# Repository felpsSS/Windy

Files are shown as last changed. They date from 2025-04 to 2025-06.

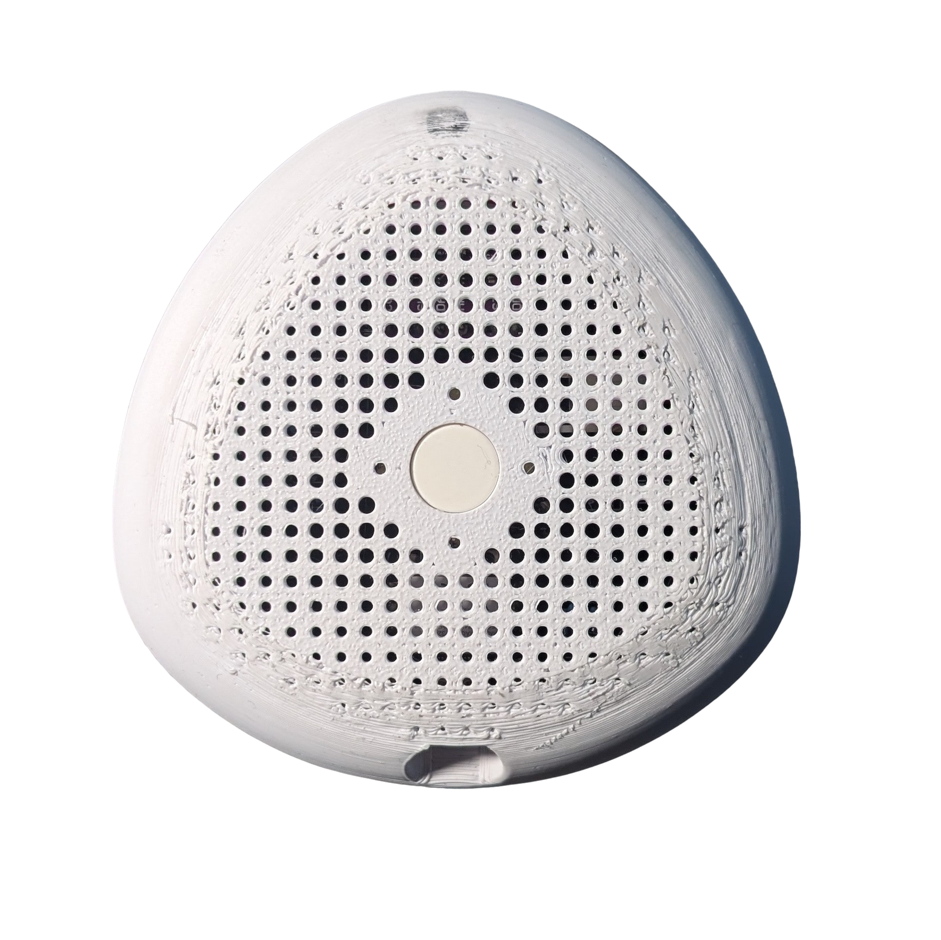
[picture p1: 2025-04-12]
media/FinalProduct.png

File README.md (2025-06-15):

# 🌬️ Windy: Build Your Air Quality Device!



Welcome to the **Windy** repository! This folder contains everything you need to build our air quality device. Whether you are a hobbyist, student, or professional, you will find useful resources here. 

## 📦 Table of Contents

- [Introduction](#introduction)
- [Features](#features)
- [Getting Started](#getting-started)
- [Hardware Components](#hardware-components)
- [Software Setup](#software-setup)
- [3D Printing](#3d-printing)
- [Mobile Application](#mobile-application)
- [PCB Design](#pcb-design)
- [Contributing](#contributing)
- [License](#license)
- [Contact](#contact)
- [Releases](#releases)

## 📜 Introduction

Air quality is vital for our health and well-being. With the **Windy** device, you can monitor air quality in real-time. This project combines various technologies, including sensors, microcontrollers, and mobile applications. 

## 🌟 Features

- Real-time air quality monitoring
- User-friendly mobile application for Android and iOS
- Open-source design for easy customization
- 3D-printed housing for a sleek look
- Easy-to-follow instructions

## 🚀 Getting Started

To get started with the **Windy** project, follow these steps:

1. **Clone the Repository**
   ```bash
   git clone https://github.com/felpsSS/Windy.git
   ```

2. **Navigate to the Directory**
   ```bash
   cd Windy
   ```

3. **Check the Documentation**
   Refer to the `docs` folder for detailed instructions.

## 🛠️ Hardware Components

To build the **Windy** device, you will need the following components:

- **ESP32 Microcontroller**: This will be the brain of your device.
- **Air Quality Sensor**: Choose a sensor that meets your needs (e.g., MQ-135).
- **Power Supply**: Ensure you have a reliable power source.
- **3D Printed Case**: You can find the design files in the `3D-Print` folder.

### Recommended Components

| Component | Description |
|---|---|
| ESP32 | Dual-core microcontroller |
| MQ-135 Sensor | Measures air quality |
| Battery Pack | For portable use |
| Jumper Wires | For connections |

## 💻 Software Setup

The software setup involves several steps:

1. **Install the Arduino IDE**: Download from the [official website](https://www.arduino.cc/en/software).
2. **Install ESP32 Board Support**: Follow the instructions in the Arduino IDE to add ESP32 support.
3. **Upload the Code**: Open the `Windy.ino` file and upload it to your ESP32.

### Libraries Required

Make sure to install the following libraries in the Arduino IDE:

- `DHT sensor library`
- `WiFi library`
- `HTTPClient library`

## 🖨️ 3D Printing

To create the housing for your **Windy** device, you will need to 3D print the case. The STL files are located in the `3D-Print` folder. 

### Printing Guidelines

- **Material**: Use PLA or ABS for durability.
- **Layer Height**: 0.2 mm for a good balance of quality and speed.
- **Infill**: 20% should be sufficient.

## 📱 Mobile Application

The **Windy** mobile application is available for both Android and iOS. It allows you to monitor air quality data from your device.

### Features of the App

- Real-time data display
- Historical data tracking
- Alerts for poor air quality
- User-friendly interface

### Installation

You can download the mobile app from the respective app stores. 

## 🛠️ PCB Design

The PCB design files are included in the repository. You can modify them as needed. 

### Design Software

We recommend using KiCAD or Eagle for PCB design. 

## 🤝 Contributing

We welcome contributions! If you want to improve the **Windy** project, please follow these steps:

1. Fork the repository.
2. Create a new branch.
3. Make your changes.
4. Submit a pull request.

## 📜 License

This project is licensed under the MIT License. See the `LICENSE` file for details.

## 📞 Contact

For questions or feedback, feel free to reach out:

- **Email**: your-email@example.com
- **GitHub**: [felpsSS](https://github.com/felpsSS)

## 🚀 Releases

For the latest updates and releases, visit our [Releases](https://github.com/felpsSS/Windy/releases) section. You can download the necessary files and execute them as needed.

---

Thank you for checking out the **Windy** project! We hope you enjoy building your air quality device. For any further questions, please refer to the documentation or contact us directly.

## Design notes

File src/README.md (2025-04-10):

# hci_air_quality

A new Flutter project.

## Getting Started

This project is a starting point for a Flutter application.

A few resources to get you started if this is your first Flutter project:

- [Lab: Write your first Flutter app](https://docs.flutter.dev/get-started/codelab)
- [Cookbook: Useful Flutter samples](https://docs.flutter.dev/cookbook)

For help getting started with Flutter development, view the
[online documentation](https://docs.flutter.dev/), which offers tutorials,
samples, guidance on mobile development, and a full API reference.

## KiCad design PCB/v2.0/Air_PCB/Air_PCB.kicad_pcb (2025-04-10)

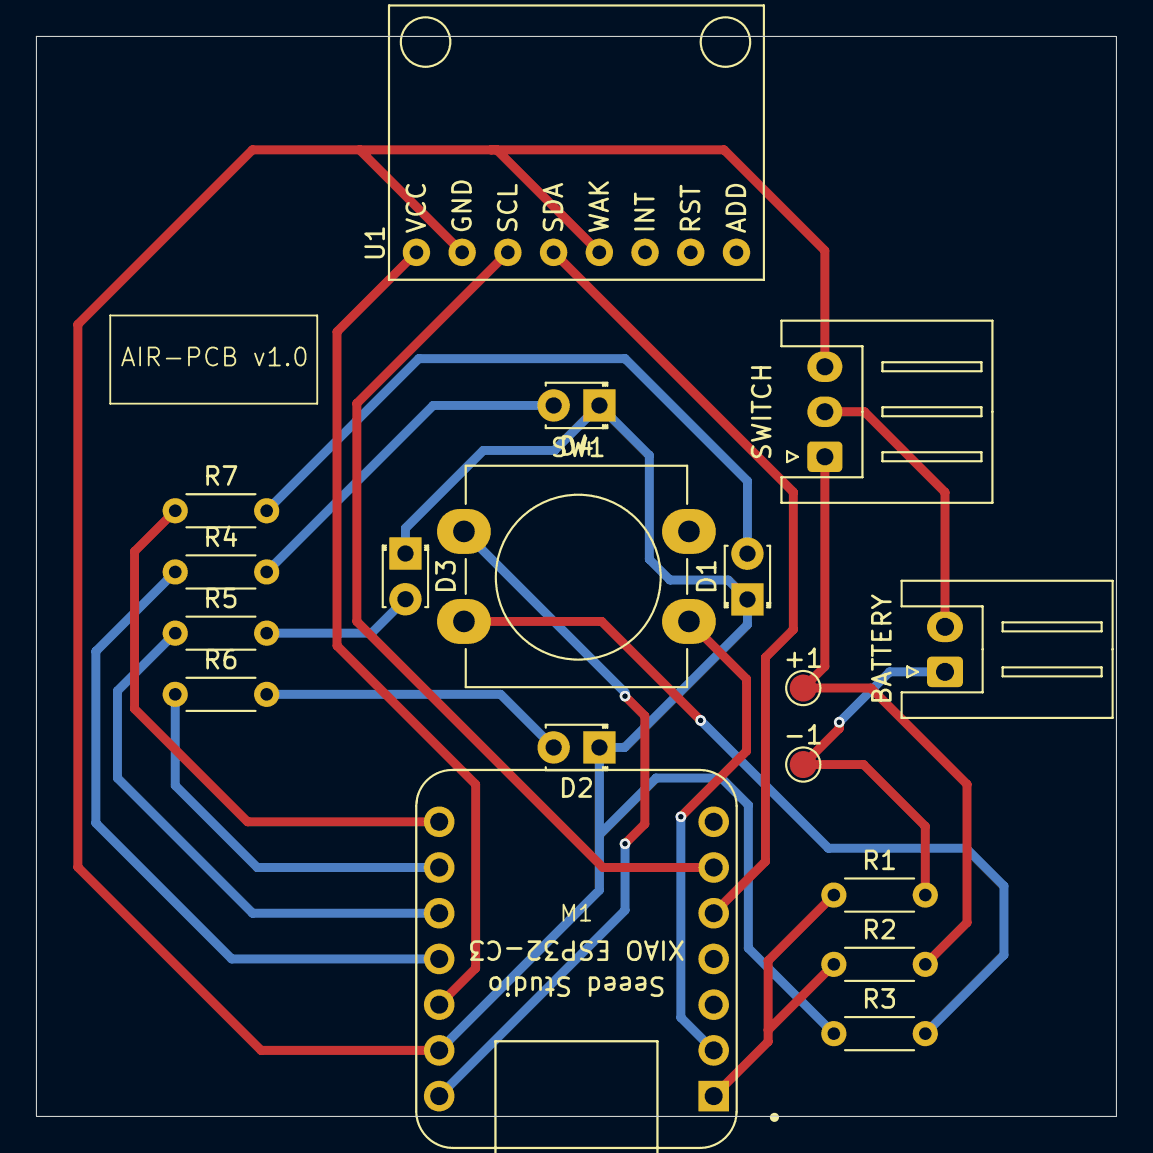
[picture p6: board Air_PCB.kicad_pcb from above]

Board: 2 copper layers, 60.0 x 60.0 mm, 18 parts (0 on the bottom side), 19 nets.

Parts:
+1: Conn_01x01_Pin; TestPoint_Pad_D1.5mm
-1: Conn_01x01_Pin; TestPoint_Pad_D1.5mm
BATTERY: Conn_01x02_Socket; JST_XH_S2B-XH-A_1x02_P2.50mm_Horizontal
D1, D2, D3, D4: LED; LED_D1.8mm_W3.3mm_H2.4mm
M1: XIAO Connector/DNP; XIAO-Generic-Thruhole-14P-2.54-21X17.8MM
R1, R2, R3, R4, R5, R6, R7: R; R_Axial_DIN0204_L3.6mm_D1.6mm_P5.08mm_Horizontal
SW1: SW_Push_Open_Dual; SW_PUSH-12mm_Wuerth-430476085716
SWITCH: Conn_01x03_Socket; JST_XH_S3B-XH-A_1x03_P2.50mm_Horizontal
U1: module_CJMCUCCS811; module_adxl345

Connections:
unnamed: +1.1, R2.2, SWITCH.1
unnamed: -1.1, BATTERY.1, R1.2
unnamed: D1.2 (A), R7.2
unnamed: D1.1 (K), D2.1 (K), D3.1 (K), D4.1 (K), M1.13 (GND), R3.1, SWITCH.3, U1.2 (GND), U1.5 (WAK)
unnamed: D2.2 (A), R6.2
unnamed: D3.2 (A), R5.2
unnamed: D4.2 (A), R4.2
unnamed: BATTERY.2, SWITCH.2
unnamed: M1.12 (3V3), U1.1 (VCC)
unnamed: M1.1 (D0/A0), R1.1, R2.1
unnamed: M1.2 (D1/A1), SW1.2
unnamed: M1.5 (D4/SDA), U1.4 (SDA)
unnamed: M1.6 (D5/SCL), U1.3 (SCL)
unnamed: M1.8 (D7/RX/SS), R7.1
unnamed: M1.9 (D8/SCK), R6.1
unnamed: M1.10 (D9/MISO), R5.1
unnamed: M1.11 (D10/MOSI), R4.1
unnamed: M1.14 (VUSB), SW1.3
unnamed: R3.2, SW1.4

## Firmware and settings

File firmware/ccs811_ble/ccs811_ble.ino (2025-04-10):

/*
XIAO ESP32C3 with CCS811 sensor

In case of errors on uploading follow these steps:

1. Plug off the USB-C
2. press BOOT on XIA0 (and hold it down)
3. Plug in the USB-C (continue to press BOOT)
4. release BOOT
5. Upload the firmware
6. press reset
*/

// CCS811 lib
#include <Adafruit_CCS811.h>
#include <BLEDevice.h>
#include <BLEUtils.h>
#include <BLEServer.h>
#include <cmath>


#define SERVICE_UUID "4fafc201-1fb5-459e-8fcc-c5c9c331914b"
#define CO2_UUID "beb5483a-36e1-4688-b7f5-ea07361b26a8"
#define TVOC_UUID "beb5483b-36e1-4688-b7f5-ea07361b26a8"
#define BATTERY_UUID "beb5483c-36e1-4688-b7f5-ea07361b26a8"
#define QINDEX_UUID "beb5483d-36e1-4688-b7f5-ea07361b26a8"


Adafruit_CCS811 ccs;
BLECharacteristic *co2Characteristic;
BLECharacteristic *tvocCharacteristic;
BLECharacteristic *batteryCharacteristic;
BLECharacteristic *qindexCharacteristic;

const int LED_1 = D8;
const int LED_2 = D9;
const int LED_3 = D10;
const int LED_4 = D7;
const int BATTERY_PIN = A0; // I'm not sure is A0
const int BUTTON = A1;
const int CHARGE = A2;

const int delay_time = 250;
unsigned long previousMillis = 0;
long interval = 10000;      // Stores the last time the counter was updated 
bool displayLights = false;     // Interval at which to count (1000 ms = 1 second)
bool charging = false;
bool deviceConnected = false;

class MyServerCallbacks: public BLEServerCallbacks {
  void onConnect(BLEServer* pServer) {
    deviceConnected = true;
  };
  
  void onDisconnect(BLEServer* pServer) {
    deviceConnected = false;
    BLEDevice::startAdvertising();
  }
};

void setup() {

  Serial.begin(9600);
  pinMode(BATTERY_PIN, INPUT);
  pinMode(BUTTON, INPUT);
  pinMode(LED_1, OUTPUT); 
  pinMode(LED_2, OUTPUT);
  pinMode(LED_3, OUTPUT);
  pinMode(LED_4, OUTPUT);
  pinMode(CHARGE, INPUT);

  Serial.println("START XIAO-ESP32C3");

  // CCS811 SETUP
  if(!ccs.begin()){
    Serial.println("Failed to start sensor! Please check your wiring. Exit.");
    while(1);
  }

  while(!ccs.available()) {
    digitalWrite(LED_1, HIGH);
    digitalWrite(LED_2, LOW);
    digitalWrite(LED_3, LOW);
    digitalWrite(LED_4, LOW);
    delay(200);
    digitalWrite(LED_1, LOW);
    digitalWrite(LED_2, HIGH);
    digitalWrite(LED_3, LOW);
    digitalWrite(LED_4, LOW);
    delay(200);
    digitalWrite(LED_1, LOW);
    digitalWrite(LED_2, LOW);
    digitalWrite(LED_3, HIGH);
    digitalWrite(LED_4, LOW);
    delay(200);
    digitalWrite(LED_1, LOW);
    digitalWrite(LED_2, LOW);
    digitalWrite(LED_3, LOW);
    digitalWrite(LED_4, HIGH);
    delay(200);
  }
  
  Serial.println("CCS ready!");

  // BLE SETUP
  BLEDevice::init("Air Quality - XIAO");
  BLEServer *pServer = BLEDevice::createServer();
  pServer->setCallbacks(new MyServerCallbacks());

  BLEService *pService = pServer->createService(SERVICE_UUID);
  co2Characteristic = pService->createCharacteristic(
                                         CO2_UUID,
                                         BLECharacteristic::PROPERTY_READ |
                                         BLECharacteristic::PROPERTY_WRITE
                                       );
  tvocCharacteristic = pService->createCharacteristic(
                                         TVOC_UUID,
                                         BLECharacteristic::PROPERTY_READ |
                                         BLECharacteristic::PROPERTY_WRITE
                                       );
  batteryCharacteristic = pService->createCharacteristic(
                                         BATTERY_UUID,
                                         BLECharacteristic::PROPERTY_READ |
                                         BLECharacteristic::PROPERTY_WRITE
                                       );
  qindexCharacteristic = pService->createCharacteristic(
                                         QINDEX_UUID,
                                         BLECharacteristic::PROPERTY_READ |
                                         BLECharacteristic::PROPERTY_WRITE
                                       );

  co2Characteristic->setValue("NULL");
  tvocCharacteristic->setValue("NULL");
  batteryCharacteristic->setValue("NULL");
  qindexCharacteristic->setValue("NULL");
  pService->start();

  BLEAdvertising *pAdvertising = BLEDevice::getAdvertising();
  pAdvertising->addServiceUUID(SERVICE_UUID);
  pAdvertising->setScanResponse(true);
  pAdvertising->setMinPreferred(0x06);  // functions that help with iPhone connections issue
  pAdvertising->setMinPreferred(0x12);
  BLEDevice::startAdvertising();
  
  Serial.println("BLE setup done!");
}




void loop() {

  // CHARGING --------------------------------------------------------------
  float pinread = digitalRead(CHARGE);
  if (pinread && !displayLights) {
    charging = true;
  }
  else{
    charging = false;
  }
  // ------------------------------------------------------------------------

  if(!deviceConnected && !charging){
    digitalWrite(LED_1, HIGH);
    digitalWrite(LED_2, LOW);
    digitalWrite(LED_3, LOW);
    digitalWrite(LED_4, LOW);
    delay(200);
    digitalWrite(LED_1, LOW);
    digitalWrite(LED_2, HIGH);
    digitalWrite(LED_3, LOW);
    digitalWrite(LED_4, LOW);
    delay(200);
    digitalWrite(LED_1, LOW);
    digitalWrite(LED_2, LOW);
    digitalWrite(LED_3, HIGH);
    digitalWrite(LED_4, LOW);
    delay(200);
    digitalWrite(LED_1, LOW);
    digitalWrite(LED_2, LOW);
    digitalWrite(LED_3, LOW);
    digitalWrite(LED_4, HIGH);
    delay(200);
    previousMillis = millis();
    displayLights = true;
    return;
  }

  // BATTERY READING ---------------------------------------------------------
  uint32_t Vbatt = 0;
  for(int i = 0; i < 16; i++) {
    Vbatt = Vbatt + analogReadMilliVolts(BATTERY_PIN); // ADC with correction   
  }
  float Vbattf = 2 * Vbatt / 16 / 1000.0; 
  Vbattf = Vbattf - 2.7;
  int battPercent = floor((Vbattf/1.3)*100);
  // ------------------------------------------------------------------------

  // SENSOR READING AND QUALITY COMPUTATION ----------------------------------
  ccs.readData();
  int co2 = ccs.geteCO2();
  int tvoc = ccs.getTVOC();

  double co2Index = max((400.0-co2)/178.0+10.0, .0);
  double tvocIndex = max((1.1-tvoc)/0.11, .0);
  int qualityIndex = min(max(ceil(co2Index + tvocIndex / 2), .0), 10.0);
  // ------------------------------------------------------------------------

  // SERIAL DEBUG LOG -------------------------------------------------------
  Serial.print(co2);
  Serial.print(" ppm");
  Serial.print(" : ");
  Serial.print(tvoc);
  Serial.print(" ppb");
  Serial.print(" : ");
  Serial.print(qualityIndex);
  Serial.print(" air quality");
  Serial.print(pinread);
  Serial.print(" : ");
  Serial.print(battPercent);
  Serial.println(" battery");
  Serial.print(charging);
  Serial.println(" charging");
  Serial.print(displayLights);
  Serial.println(" lights");
  // ------------------------------------------------------------------------


  // LIGHTS SWITCH ON BUTTON PRESS ------------------------------------------
  unsigned long currentMillis = millis();
  if (currentMillis - previousMillis >= interval) {
    LightsOFF();
    displayLights = false;
    interval = 10000;
  }
  
  if(displayLights){
    LightsON(qualityIndex);
  }

  if(charging){
    ShowCharge(battPercent);
  }

  if(digitalRead(BUTTON)){
    previousMillis = currentMillis;
    displayLights = true;
  }
  // ------------------------------------------------------------------------


  // BLE VALUE SENDING ------------------------------------------------------
  if (deviceConnected) {
    batteryCharacteristic->setValue(battPercent);
    batteryCharacteristic->notify();

    co2Characteristic->setValue(co2);
    co2Characteristic->notify();

    tvocCharacteristic->setValue(tvoc);
    tvocCharacteristic->notify();

    qindexCharacteristic->setValue(qualityIndex);
    qindexCharacteristic->notify();
  }
  // ------------------------------------------------------------------------

  delay(delay_time);
}

void LightsOFF(){
  for(int i = 0; i<4; i++){
    int span = 8;
    if(i==3){
      span = 17;
    }
    digitalWrite(span+i, LOW);
  }
}

void LightsON(int index){
  if (index <= 2){
    digitalWrite(LED_1, HIGH);
    digitalWrite(LED_2, LOW);
    digitalWrite(LED_3, LOW);
    digitalWrite(LED_4, LOW);
  } else if(index > 2 && index <= 5){
    digitalWrite(LED_1, HIGH);
    digitalWrite(LED_2, HIGH);
    digitalWrite(LED_3, LOW);
    digitalWrite(LED_4, LOW);
  } else if(index > 5 && index <= 7){
    digitalWrite(LED_1, HIGH);
    digitalWrite(LED_2, HIGH);
    digitalWrite(LED_3, HIGH);
    digitalWrite(LED_4, LOW);
  } else {
    digitalWrite(LED_1, HIGH);
    digitalWrite(LED_2, HIGH);
    digitalWrite(LED_3, HIGH);
    digitalWrite(LED_4, HIGH); 
  }
}

void ShowCharge(int percentage){

  for(int i = 0; i<4; i++){
    int span = 8;
    if(i==3){
      span = 17;
    }
    digitalWrite(span+i, LOW);
  }
  delay(750);

  if(percentage>99){
    
    if(digitalRead(BUTTON)){
      unsigned long currentMillis = millis();
      previousMillis = currentMillis;
      displayLights = true;
      return;
    }

    for(int i = 0; i<4; i++){
      int span = 8;
      if(i==3){
        span = 17;
      }
      digitalWrite(span+i, HIGH);
    }
    return;
  }
  
  int percent_int = floor((percentage)/25)+1;
  for(int i = 0; i<percent_int; i++){

    if(i==4){
      break;
    }

    if(digitalRead(BUTTON)){
      unsigned long currentMillis = millis();
      previousMillis = currentMillis;
      displayLights = true;
      return;
    }

    int span = 8;
    if(i==3){
      span = 17;
    }
    digitalWrite(span+i, HIGH);
    delay(250);
  }

}

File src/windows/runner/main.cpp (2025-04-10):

#include <flutter/dart_project.h>
#include <flutter/flutter_view_controller.h>
#include <windows.h>

#include "flutter_window.h"
#include "utils.h"

int APIENTRY wWinMain(_In_ HINSTANCE instance, _In_opt_ HINSTANCE prev,
                      _In_ wchar_t *command_line, _In_ int show_command) {
  // Attach to console when present (e.g., 'flutter run') or create a
  // new console when running with a debugger.
  if (!::AttachConsole(ATTACH_PARENT_PROCESS) && ::IsDebuggerPresent()) {
    CreateAndAttachConsole();
  }

  // Initialize COM, so that it is available for use in the library and/or
  // plugins.
  ::CoInitializeEx(nullptr, COINIT_APARTMENTTHREADED);

  flutter::DartProject project(L"data");

  std::vector<std::string> command_line_arguments =
      GetCommandLineArguments();

  project.set_dart_entrypoint_arguments(std::move(command_line_arguments));

  FlutterWindow window(project);
  Win32Window::Point origin(10, 10);
  Win32Window::Size size(1280, 720);
  if (!window.Create(L"hci_air_quality", origin, size)) {
    return EXIT_FAILURE;
  }
  window.SetQuitOnClose(true);

  ::MSG msg;
  while (::GetMessage(&msg, nullptr, 0, 0)) {
    ::TranslateMessage(&msg);
    ::DispatchMessage(&msg);
  }

  ::CoUninitialize();
  return EXIT_SUCCESS;
}
